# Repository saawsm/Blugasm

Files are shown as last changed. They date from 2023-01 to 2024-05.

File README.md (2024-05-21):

# Blugasm - A Bluetooth enabled Nogasm

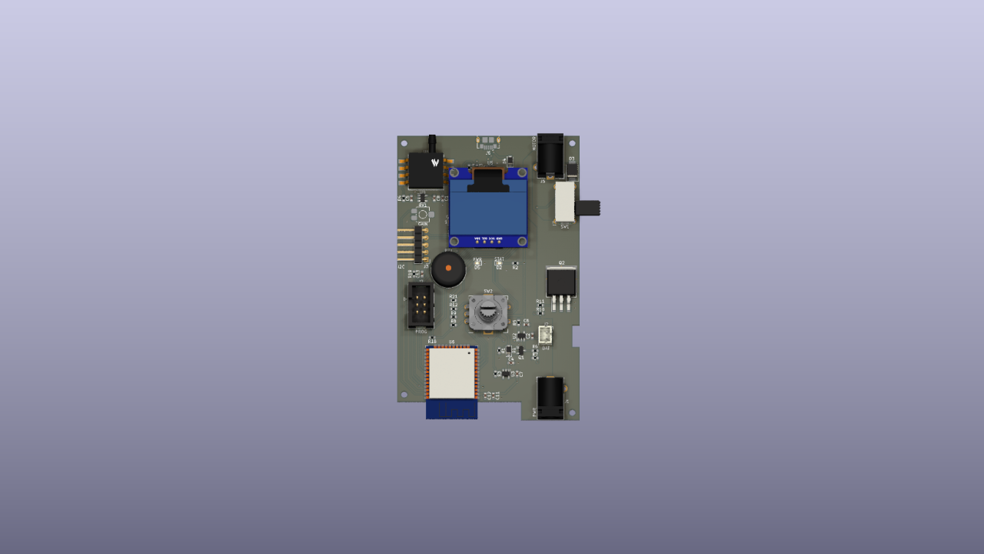
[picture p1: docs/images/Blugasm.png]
Blugasm


This project aims to predict and detect orgasms by using a pressure sensor (and optionally, additional I2C sensors such as SpO2 and/or GSR sensor) while controlling a vibrator.

The original design and concept comes from the [nogasm](https://github.com/nogasm/nogasm). It improves upon it by making it battery operated and Bluetooth enabled, thanks to the ESP-32 microcontroller.

## Acknowledgements
The design of this board was inspired/based off the [nogasm board](https://github.com/nogasm/nogasm).

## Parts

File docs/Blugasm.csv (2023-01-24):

Ref | Qty | Value | Description | MPN | MOUSER | LCSC
BZ1 | 1 | Buzzer | Buzzer, polarized | IE122303-1 | 497-IE122303-1
C1 | 1 | 10nF | Unpolarized capacitor, small symbol | CL10B103KB8NNNC | 187-CL10B103KB8NNNC | C1589
C2, C4, C6, C7 | 4 | 10uF | Unpolarized capacitor, small symbol | CL10A106MA8NRNC | 187-CL10A106MA8NRNC | C96446
C3 | 1 | 1uF | Unpolarized capacitor, small symbol | CL10B105KA8NFNC | 187-CL10B105KA8NFNC | C307479
C5 | 1 | 330nF | Unpolarized capacitor, small symbol | CL10B334KO8NNNC | 187-CL10B334KO8NNNC | C159798
C8, C9, C12, C13, C14, C15 | 6 | 100nF | Unpolarized capacitor, small symbol | CL10B104KB8NNWC | 187-CL10B104KB8NNNC | C1591
C10 | 1 | 4.7uF | Unpolarized capacitor, small symbol | CL10A475KQ8NNWC | 187-CL10A475KQ8NNWC | C3849923
C11 | 1 | 22uF | Unpolarized capacitor, small symbol | CL10A106MA8NRNC | 187-CL10A106MA8NRNC | C96446
D1, D4 | 2 | SS24FL | Schottky diode | SS24FL | 512-SS24FL | C894433
D2 | 1 | GREEN | Light emitting diode | 150060VS75000 | 710-150060VS75000
D3 | 1 | SSB44-E3 | Schottky diode, small symbol | SSB44-E3/52T | 625-SSB44-E3 | C466999
D5 | 1 | RED | Light emitting diode | 150060RS75000 | 710-150060RS75000
J1 | 1 | PWR | DC Barrel Jack with an internal switch | PJ-102AH | 490-PJ-102AH
J2 | 1 | BAT | Generic connector, single row, 01x02, script generated (kicad-library-utils/schlib/autogen/connector/)
J3 | 1 | I2C | Generic connector, single row, 01x05, script generated (kicad-library-utils/schlib/autogen/connector/)
J4 | 1 | OLED | 0.96" OLED Module I2C
J5 | 1 | MOTOR | DC Barrel Jack with an internal switch | PJ-102AH | 490-PJ-102AH
J6 | 1 | USB_B_Micro | USB Micro Type B connector | USB3076-30-A | 640-USB3076-30-A
J7 | 1 | PROG | Generic connector, double row, 02x03, odd/even pin numbering scheme (row 1 odd numbers, row 2 even numbers), script generated (kicad-library-utils/schlib/autogen/connector/)
Q1 | 1 | DMG3415U | P-MOSFET transistor, gate/source/drain | DMG3415UQ-7 | 621-DMG3415UQ-7 | C459537
Q2 | 1 | PHB32N06LT,118 | N-MOSFET transistor, gate/drain/source | PHB32N06LT,118 | 771-PHB32N06LT118 | C552626
Q3, Q4 | 2 | SS8050-G | NPN transistor, base/emitter/collector | SS8050-G | 750-SS8050-G | C164886
R1, R3, R6, R7 | 4 | 100k | Resistor | RC0603FR-07100KL | 603-RC0603FR-07100KL | C14675
R2, R5, R20, R22 | 4 | 4.7k | Resistor | RC0603FR-074K7L | 603-RC0603FR-074K7L | C99782
R4 | 1 | 750 | Resistor | RC0603FR-07750RL | 603-RC0603FR-07750RL | C114635
R10, R12, R15, R16, R18, R19 | 6 | 10k | Resistor | RC0603FR-0710KL | 603-RC0603FR-0710KL | C98220
R11, R23 | 2 | 100 | Resistor | RC0603FR-07100RL | 603-RC0603FR-07100RL | C105588
R13 | 1 | 22.1k | Resistor | RC0603FR-0722K1L | 603-RC0603FR-0722K1L | C137768
R14 | 1 | 47.5k | Resistor | RC0603FR-1047K5L | 603-RC0603FR-1047K5L | C4149630
R17, R21 | 2 | 1k | Resistor | RC0603FR-071KL | 603-RC0603FR-071KL | C22548
RV1 | 1 | GAIN | Trim-potentiometer | ST-4ETB103 | 229-ST-4ETB103 | C2922095
SW1 | 1 | PWR | Switch, dual pole double throw, separate symbols | EG2219 | 612-EG2219 | C3664594
SW2 | 1 | PEC11R-4220K-S0024 | Rotary encoder, dual channel, incremental quadrate outputs, with switch | PEC11R-4220K-S0024 | 652-PEC11R-4220K-S24
U1 | 1 | MP3V5050GP | 0 to 50 kPa Gauge Pressure Sensor | MP3V5050GP | 841-MP3V5050GP
U2 | 1 | MCP73831-2-OT | Single cell, Li-Ion/Li-Po charge management controller, 4.20V, Tri-State Status Output, in SOT23-5 package | MCP73831T-2ACI/OT | 579-MCP73831T-2ACIOT | C424093
U3 | 1 | AP2112K-3.3 | 600mA low dropout linear regulator, with enable pin, 3.8V-6V input voltage range, 3.3V fixed positive output, SOT-23-5 | AP2112K-3.3TRG1 | 621-AP2112K-3.3TRG1 | C51118
U4 | 1 | MCP6001-OT | 1MHz, Low-Power Op Amp, SOT-23-5 | MCP6001RT-I/OT | 579-MCP6001RT-I/OT | C154973
U5 | 1 | CP2102N-A02-GQFN24 | USB to UART master bridge, QFN-24 | CP2102N-A02-GQFN24R | 634-CP2102NA02QFN24R | C969151
U6 | 1 | ESP32-WROOM-32E | RF Module, ESP32-D0WD SoC, Wi-Fi 802.11b/g/n, Bluetooth, BLE, 32-bit, 2.7-3.6V, onboard antenna, SMD | ESP32-WROOM-32E-N16 | 356-ESP32WRM32E128PH | C701343

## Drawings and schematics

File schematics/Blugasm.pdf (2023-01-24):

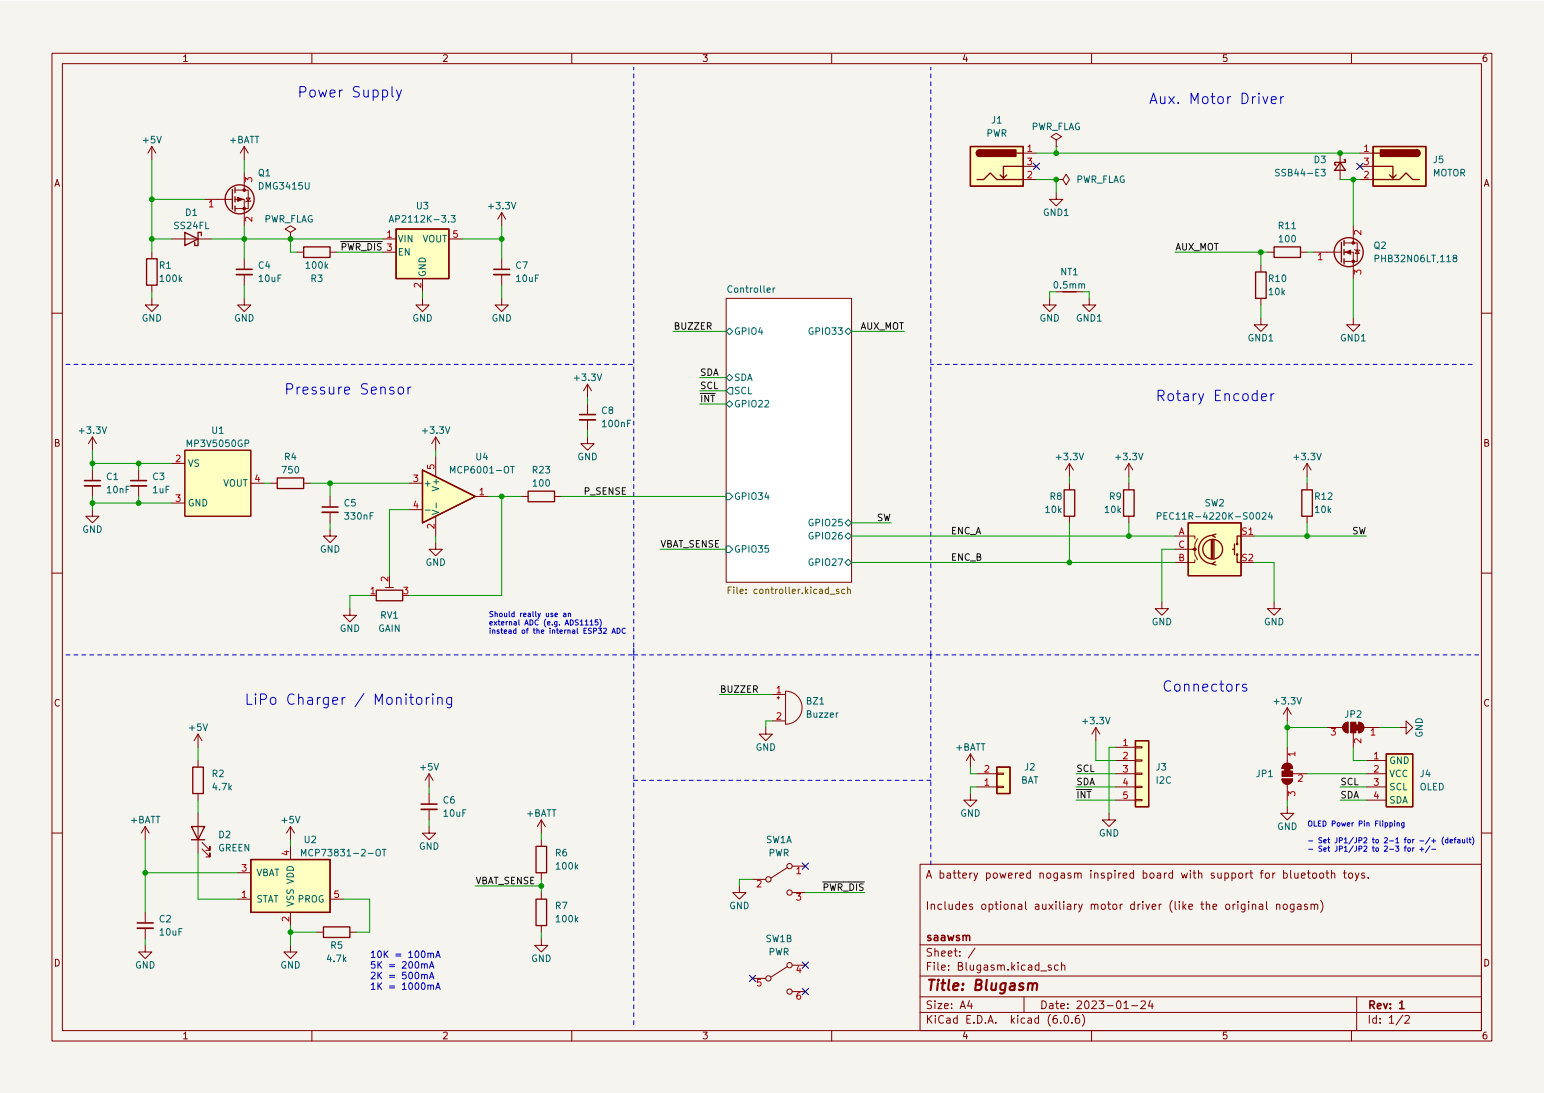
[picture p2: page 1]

instead of the internal ESP32 ADC Pressure Sensor

Should really use an
external ADC (e.g. ADS1115)

- Set JP1/JP2 to 2-1 for -/+ (default)
- Set JP1/JP2 to 2-3 for +/-

A battery powered nogasm inspired board with support for bluetooth toys.

Includes optional auxiliary motor driver (like the original nogasm)

File: Blugasm.kicad_sch Sheet: / saawsm

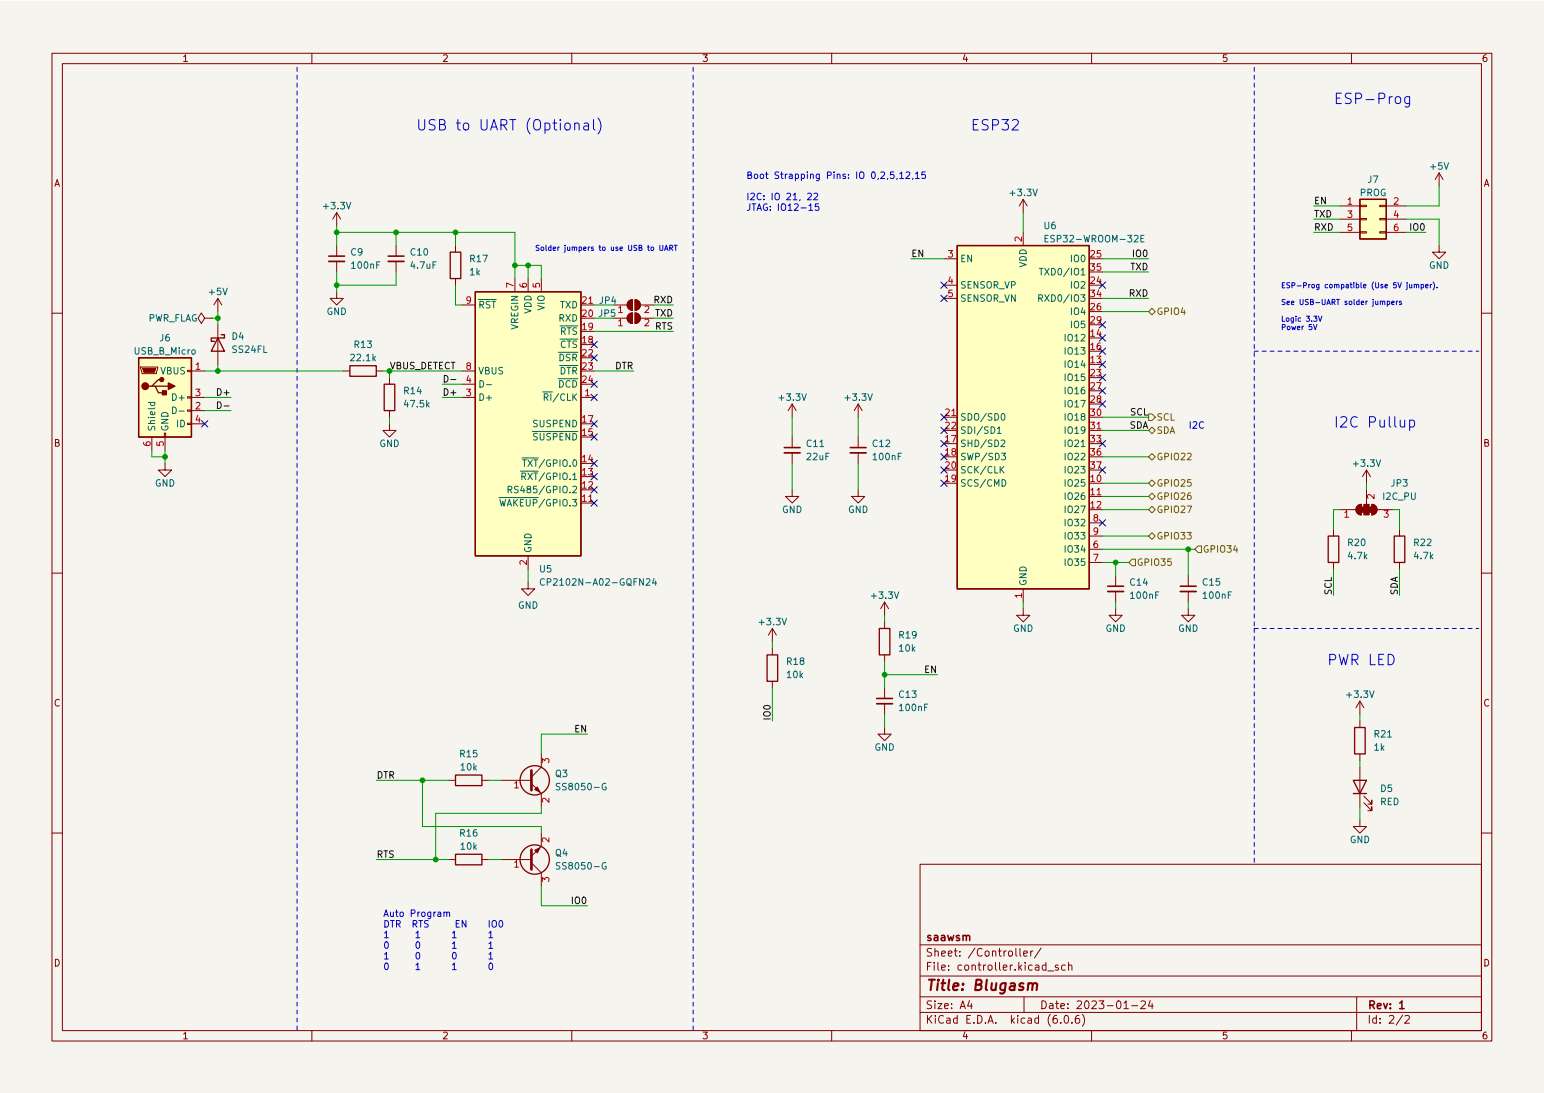
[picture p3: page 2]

Solder jumpers to use USB to UART USB to UART (Optional)

Power 5V Boot Strapping Pins: IO 0,2,5,12,15

2 SCK/CLK 20 SDO/SD0 21 SDI/SD1 22

ESP-Prog compatible (Use 5V jumper). See USB-UART solder jumpers Logic 3.3V

2 RXD 20 TXD 21 ~{DSR}22 ~{DTR}23 ~{DCD}24 D+ 3 D- 4 VIO

File: controller.kicad_sch Sheet: /Controller/ saawsm

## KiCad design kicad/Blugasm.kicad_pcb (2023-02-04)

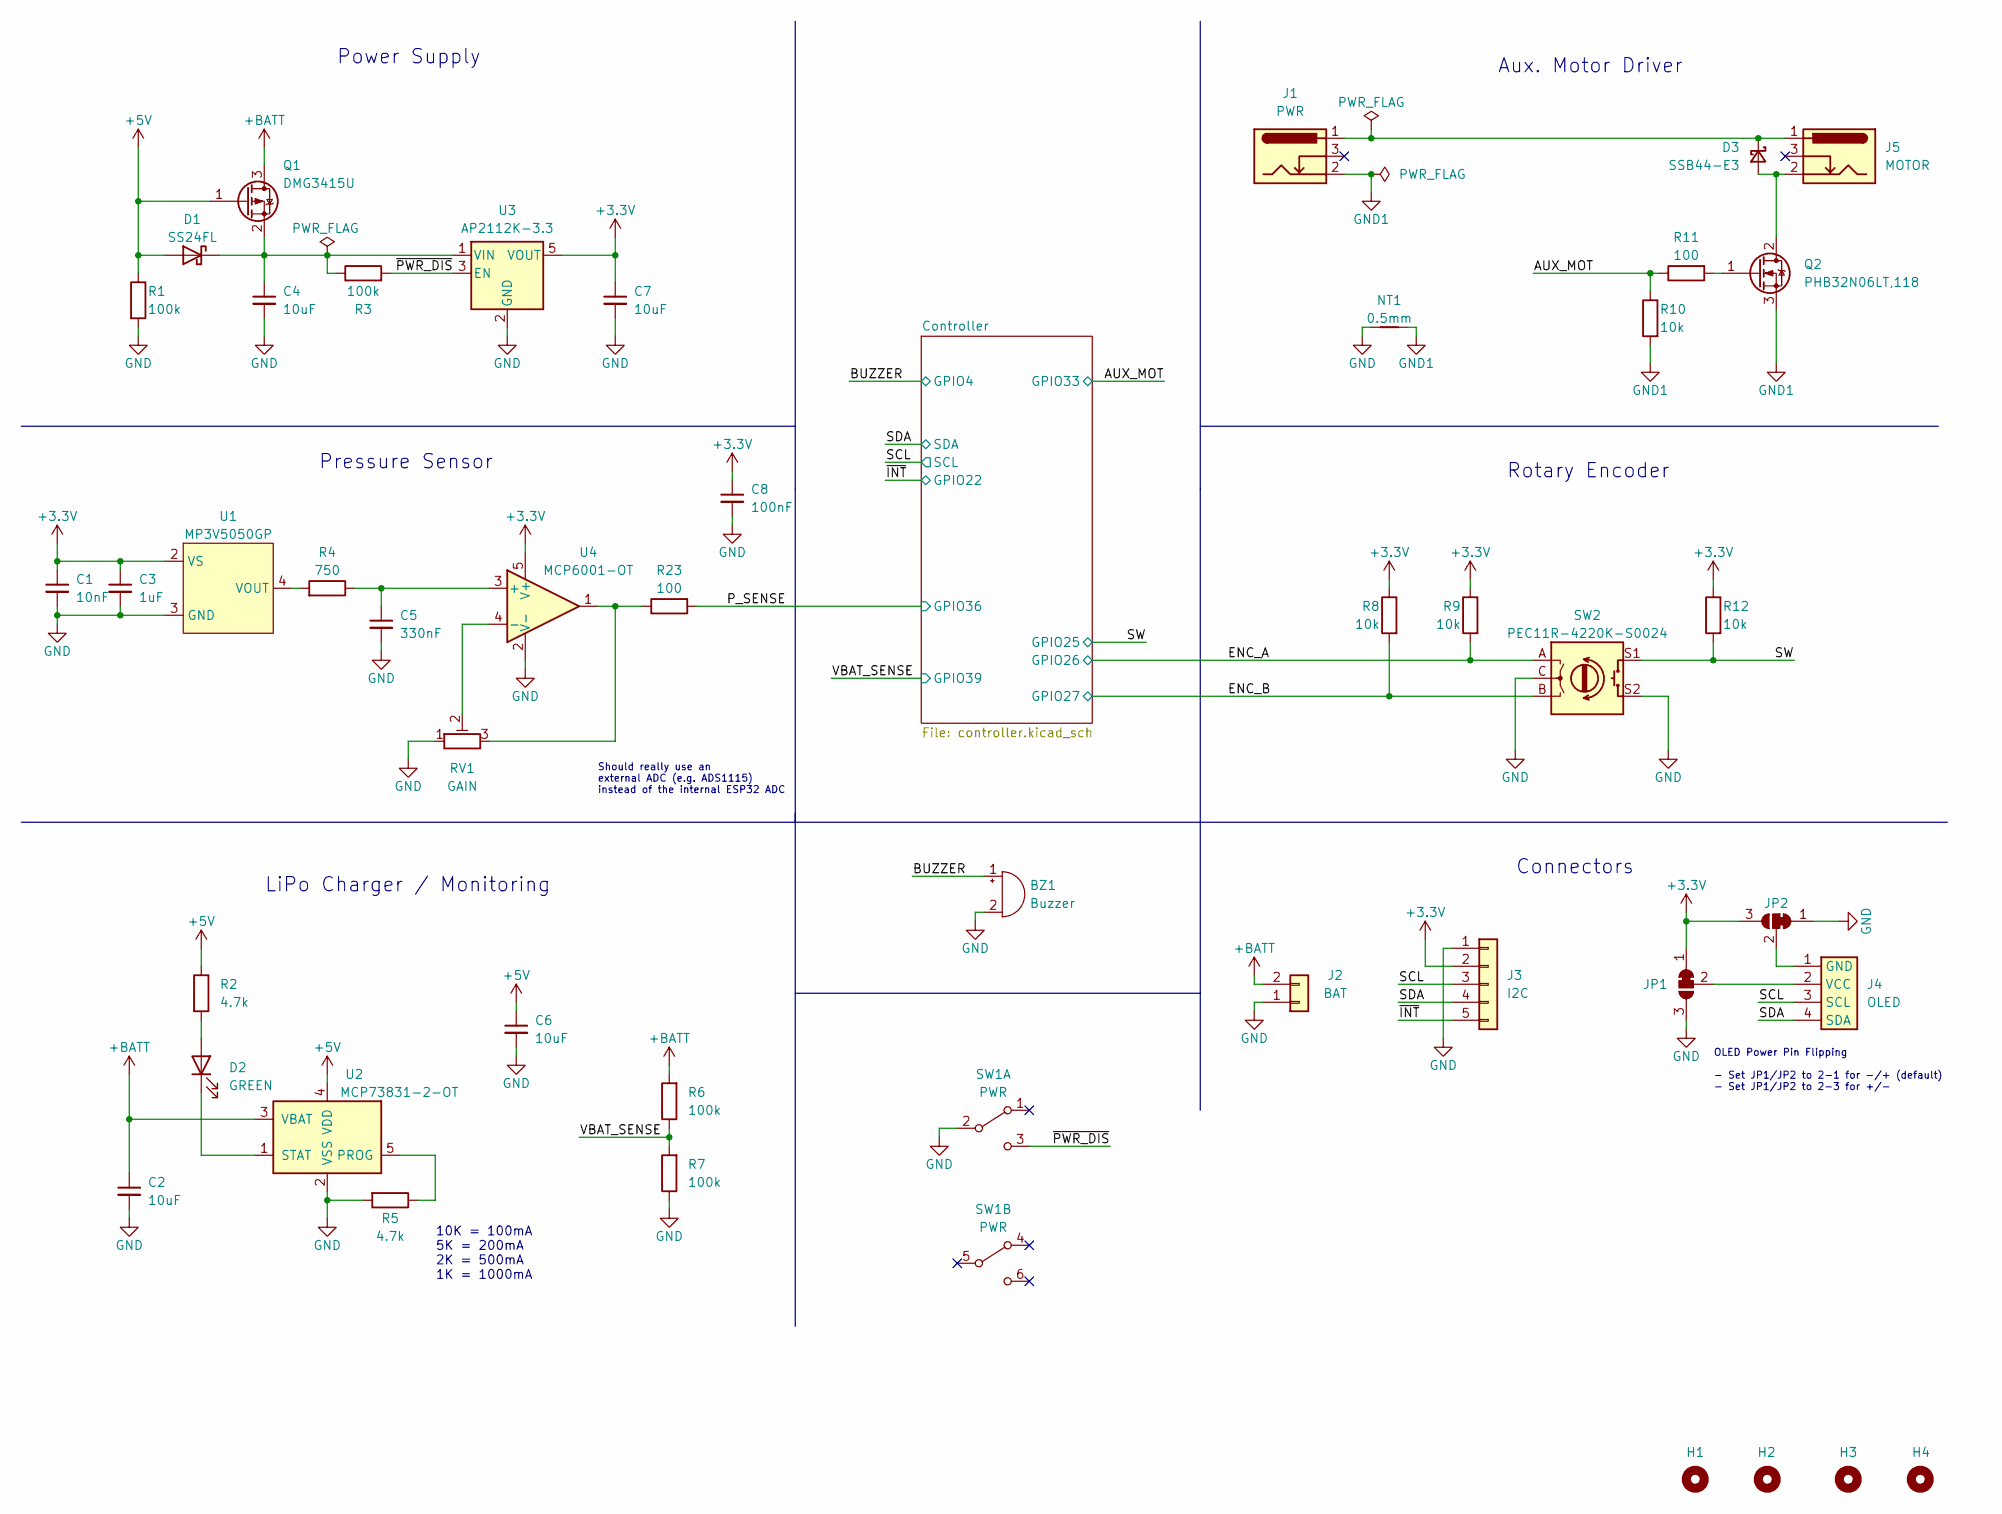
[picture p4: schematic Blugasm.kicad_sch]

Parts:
BZ1: Buzzer; Buzzer_12x9.5RM7.6; MPN IE122303-1; MOUSER 497-IE122303-1
C1: 10nF; C_0603_1608Metric; MPN CL10B103KB8NNNC; LCSC C1589
C2, C4, C6, C7: 10uF; C_0603_1608Metric; MPN CL10A106MA8NRNC; LCSC C96446
C3: 1uF; C_0603_1608Metric; MPN CL10B105KA8NFNC; LCSC C307479
C5: 330nF; C_0603_1608Metric; MPN CL10B334KO8NNNC; LCSC C159798
C8: 100nF; C_0603_1608Metric; MPN CL10B104KB8NNWC; LCSC C1591
D1: SS24FL; D_SOD-123F; MPN SS24FL; LCSC C894433
D2: GREEN; LED_0603_1608Metric; MPN 150060VS75000; MOUSER 710-150060VS75000
D3: SSB44-E3; D_SMB; MPN SSB44-E3/52T; LCSC C466999
H1, H2, H3, H4: MountingHole; MountingHole_2.2mm_M2
J1: PWR; BarrelJack_CUI_PJ-102AH_Horizontal; MPN PJ-102AH; MOUSER 490-PJ-102AH
J2: BAT; JST_PH_B2B-PH-K_1x02_P2.00mm_Vertical
J3: I2C; PinHeader_1x05_P2.54mm_Horizontal
J4: OLED; OLED_I2C
J5: MOTOR; BarrelJack_CUI_PJ-102AH_Horizontal; MPN PJ-102AH; MOUSER 490-PJ-102AH
JP1, JP2: SolderJumper_3_Bridged12; SolderJumper-3_P1.3mm_Bridged12_Pad1.0x1.5mm_NumberLabels
NT1: 0.5mm; NetTie-2_SMD_Pad0.5mm
Q1: DMG3415U; SOT-23; MPN DMG3415UQ-7; LCSC C459537
Q2: PHB32N06LT,118; TO-263-3_TabPin2; MPN PHB32N06LT,118; LCSC C552626
R1, R3, R6, R7: 100k; R_0603_1608Metric; MPN RC0603FR-07100KL; LCSC C14675
R2, R5: 4.7k; R_0603_1608Metric; MPN RC0603FR-074K7L; LCSC C99782
R4: 750; R_0603_1608Metric; MPN RC0603FR-07750RL; LCSC C114635
R8, R9, R10, R12: 10k; R_0603_1608Metric; MPN RC0603FR-0710KL; LCSC C98220
R11, R23: 100; R_0603_1608Metric; MPN RC0603FR-07100RL; LCSC C105588
RV1: GAIN; ST-4EB; MPN ST-4ETB103; LCSC C2922095
SW1: PWR; SW_E-Switch_EG2219_DPDT_Angled; MPN EG2219; MOUSER 612-EG2219
SW2: PEC11R-4220K-S0024; Rotary_Encoder_Switched_PEC11R; MPN PEC11R-4220K-S0024; MOUSER 652-PEC11R-4220K-S24
U1: MP3V5050GP; MP3V5050; MPN MP3V5050GP; MOUSER 841-MP3V5050GP
U2: MCP73831-2-OT; SOT-23-5; MPN MCP73831T-2ACI/OT; LCSC C424093
U3: AP2112K-3.3; SOT-23-5; MPN AP2112K-3.3TRG1; LCSC C51118
U4: MCP6001-OT; SOT-23-5; MPN MCP6001RT-I/OT; MOUSER 579-MCP6001RT-I/OT

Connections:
+3.3V: C1.1, C3.1, C7.1, C8.1, J3.2, JP1.1 (A), JP2.3 (B), R8.1, R9.1, R12.1, U1.2 (VS), U3.5 (VOUT), U4.5 (V+); also elsewhere on the board
+5V: C6.1, D1.2 (A), Q1.1 (G), R1.1, R2.1, U2.4 (VDD); also elsewhere on the board
+BATT: C2.1, J2.2, Q1.3 (D), R6.2, U2.3 (VBAT)
/AUX_MOT: R10.1, R11.1; also elsewhere on the board
/BUZZER: BZ1.1 (-); also elsewhere on the board
/ENC_A: R9.2, SW2.A; also elsewhere on the board
/ENC_B: R8.2, SW2.B; also elsewhere on the board
/P_SENSE: R23.2; also elsewhere on the board
/SCL: J3.3, J4.3 (SCL); also elsewhere on the board
/SDA: J3.4, J4.4 (SDA); also elsewhere on the board
/SW: R12.2, SW2.S1; also elsewhere on the board
/VBAT_SENSE: R6.1, R7.2; also elsewhere on the board
/~INT: J3.5; also elsewhere on the board
/~PWR_DIS: R3.2, SW1.3 (C), U3.3 (EN)
GND: BZ1.2 (+), C1.2, C2.2, C3.2, C4.2, C5.2, C6.2, C7.2, C8.2, J2.1, J3.1, JP1.3 (B), JP2.1 (A), NT1.1, R1.2, R5.2, R7.1, RV1.1, SW1.2 (B), SW2.C, SW2.S2, U1.3 (GND), U2.2 (VSS), U3.2 (GND), U4.2 (V-); also elsewhere on the board
GND1: J1.2, NT1.2, Q2.3 (S), R10.2
unnamed: C4.1, D1.1 (K), Q1.2 (S), R3.1, U3.1 (VIN)
unnamed: C5.1, R4.1, U4.3 (+)
unnamed: D2.1 (K), U2.1 (STAT)
unnamed: D2.2 (A), R2.2
unnamed: D3.1 (K), J1.1, J5.1
unnamed: D3.2 (A), J5.2, Q2.2 (D)
unnamed: J4.1 (GND), JP2.2 (C)
unnamed: J4.2 (VCC), JP1.2 (C)
unnamed: Q2.1 (G), R11.2
unnamed: R4.2, U1.4 (VOUT)
unnamed: R5.1, U2.5 (PROG)
unnamed: R23.1, RV1.3, U4.1
unnamed: RV1.2, U4.4 (-)

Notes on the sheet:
Should really use an external ADC (e.g. ADS1115) instead of the internal ESP32 ADC
Aux. Motor Driver
Connectors
OLED Power Pin Flipping - Set JP1/JP2 to 2-1 for -/+ (default) - Set JP1/JP2 to 2-3 for +/-
10K = 100mA 5K = 200mA 2K = 500mA 1K = 1000mA
Rotary Encoder
Pressure Sensor
Power Supply
LiPo Charger / Monitoring

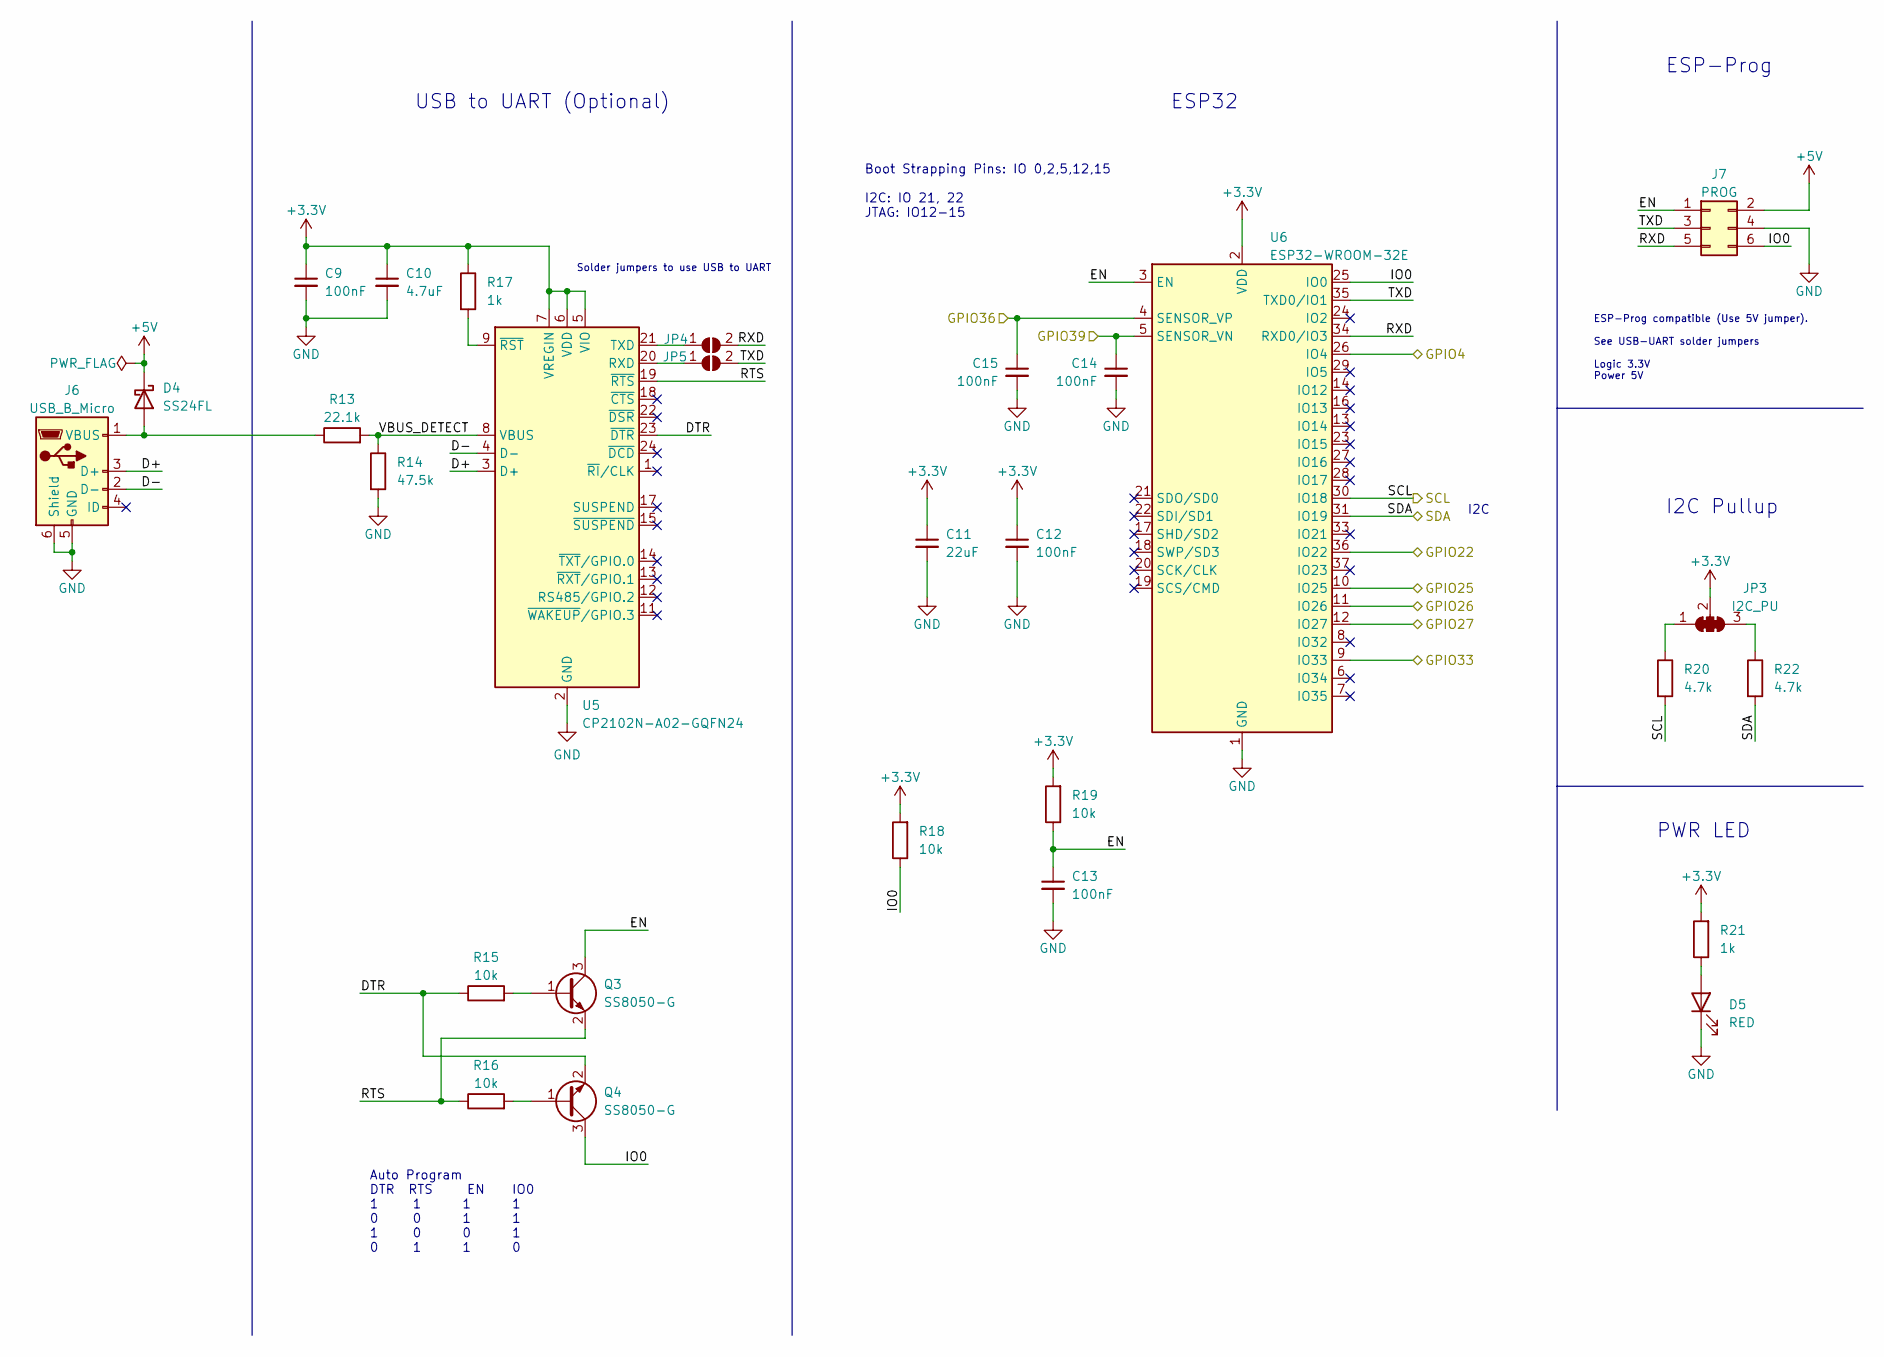
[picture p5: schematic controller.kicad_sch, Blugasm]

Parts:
C9, C12, C13, C14, C15: 100nF; C_0603_1608Metric; MPN CL10B104KB8NNWC; LCSC C1591
C10: 4.7uF; C_0603_1608Metric; MPN CL10A475KQ8NNWC; LCSC C3849923
C11: 22uF; C_0603_1608Metric; MPN CL10A106MA8NRNC; LCSC C96446
D4: SS24FL; D_SOD-123F; MPN SS24FL; LCSC C894433
D5: RED; LED_0603_1608Metric; MPN 150060RS75000; MOUSER 710-150060RS75000
J6: USB_B_Micro; USB_Micro-B_GCT_USB3076-30-A; MPN USB3076-30-A; MOUSER 640-USB3076-30-A
J7: PROG; IDC-Header_2x03_P2.54mm_Vertical
JP3: I2C_PU; SolderJumper-3_P1.3mm_Bridged123_Pad1.0x1.5mm_NumberLabels
JP4: UART_TXD; SolderJumper-2_P1.3mm_Open_RoundedPad1.0x1.5mm
JP5: UART_RXD; SolderJumper-2_P1.3mm_Open_RoundedPad1.0x1.5mm
Q3, Q4: SS8050-G; SOT-23; MPN SS8050-G; LCSC C164886
R13: 22.1k; R_0603_1608Metric; MPN RC0603FR-0722K1L; LCSC C137768
R14: 47.5k; R_0603_1608Metric; MPN RC0603FR-1047K5L; LCSC C4149630
R15, R16, R18, R19: 10k; R_0603_1608Metric; MPN RC0603FR-0710KL; LCSC C98220
R17, R21: 1k; R_0603_1608Metric; MPN RC0603FR-071KL; LCSC C22548
R20, R22: 4.7k; R_0603_1608Metric; MPN RC0603FR-074K7L; LCSC C99782
U5: CP2102N-A02-GQFN24; QFN-24-1EP_4x4mm_P0.5mm_EP2.6x2.6mm; MPN CP2102N-A02-GQFN24R; LCSC C969151
U6: ESP32-WROOM-32E; ESP32-WROOM-32; MPN ESP32-WROOM-32E-N16; LCSC C701343

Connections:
+3.3V: C9.1, C10.1, C11.1, C12.1, JP3.2 (C), R17.1, R18.2, R19.2, R21.2, U5.5 (VIO), U5.6 (VDD), U5.7 (VREGIN), U6.2 (VDD); also elsewhere on the board
+5V: D4.1 (K), J7.2; also elsewhere on the board
/AUX_MOT: U6.9 (IO33); also elsewhere on the board
/BUZZER: U6.26 (IO4); also elsewhere on the board
/Controller/D+: J6.3 (D+), U5.3 (D+)
/Controller/D-: J6.2 (D-), U5.4 (D-)
/Controller/DTR: Q4.2 (E), R15.1, U5.23 (~DTR)
/Controller/EN: C13.1, J7.1, Q3.3 (C), R19.1, U6.3 (EN)
/Controller/IO0: J7.6, Q4.3 (C), R18.1, U6.25 (IO0)
/Controller/RTS: Q3.2 (E), R16.1, U5.19 (~RTS)
/Controller/RXD: J7.5, JP4.2 (B), U6.34 (RXD0/IO3)
/Controller/TXD: J7.3, JP5.2 (B), U6.35 (TXD0/IO1)
/Controller/VBUS_DETECT: R13.2, R14.1, U5.8 (VBUS)
/ENC_A: U6.11 (IO26); also elsewhere on the board
/ENC_B: U6.12 (IO27); also elsewhere on the board
/P_SENSE: C15.1, U6.4 (SENSOR_VP); also elsewhere on the board
/SCL: R20.2, U6.30 (IO18); also elsewhere on the board
/SDA: R22.2, U6.31 (IO19); also elsewhere on the board
/SW: U6.10 (IO25); also elsewhere on the board
/VBAT_SENSE: C14.1, U6.5 (SENSOR_VN); also elsewhere on the board
/~INT: U6.36 (IO22); also elsewhere on the board
GND: C9.2, C10.2, C11.2, C12.2, C13.2, C14.2, C15.2, D5.1 (K), J6.5 (GND), J6.6 (Shield), J7.4, R14.2, U5.2 (GND), U5.25 (GND), U6.1 (GND), U6.15 (GND), U6.38 (GND), U6.39 (GND); also elsewhere on the board
unnamed: D4.2 (A), J6.1 (VBUS), R13.1
unnamed: D5.2 (A), R21.1
unnamed: JP3.1 (A), R20.1
unnamed: JP3.3 (B), R22.1
unnamed: JP4.1 (A), U5.21 (TXD)
unnamed: JP5.1 (A), U5.20 (RXD)
unnamed: Q3.1 (B), R15.2
unnamed: Q4.1 (B), R16.2
unnamed: R17.2, U5.9 (~RST)

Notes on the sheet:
ESP32
PWR LED
ESP-Prog
I2C Pullup
Solder jumpers to use USB to UART
I2C
USB to UART (Optional)
Boot Strapping Pins: IO 0,2,5,12,15 I2C: IO 21, 22 JTAG: IO12-15
Auto Program DTR RTS EN IO0 1 1 1 1 0 0 1 1 1 0 0 1 0 1 1 0
ESP-Prog compatible (Use 5V jumper). See USB-UART solder jumpers Logic 3.3V Power 5V

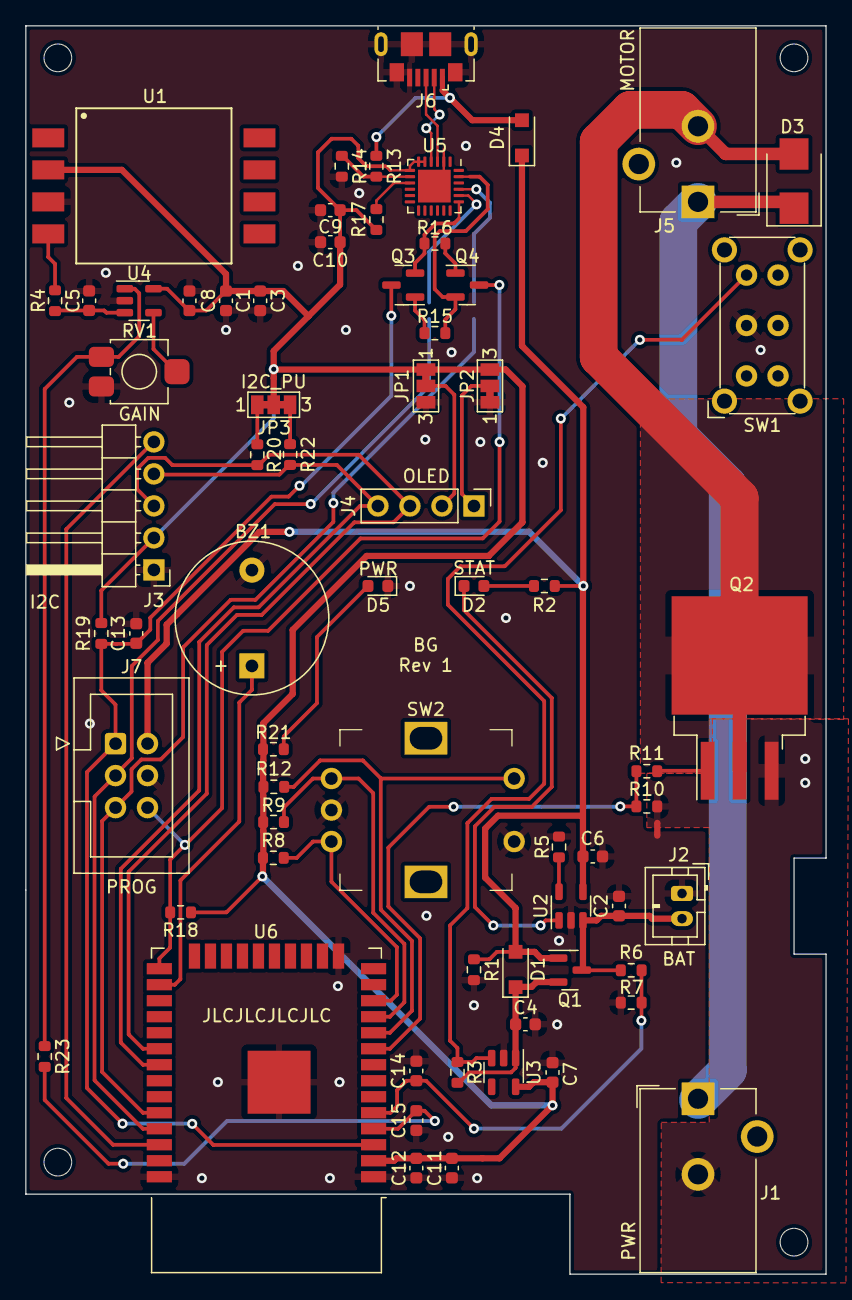
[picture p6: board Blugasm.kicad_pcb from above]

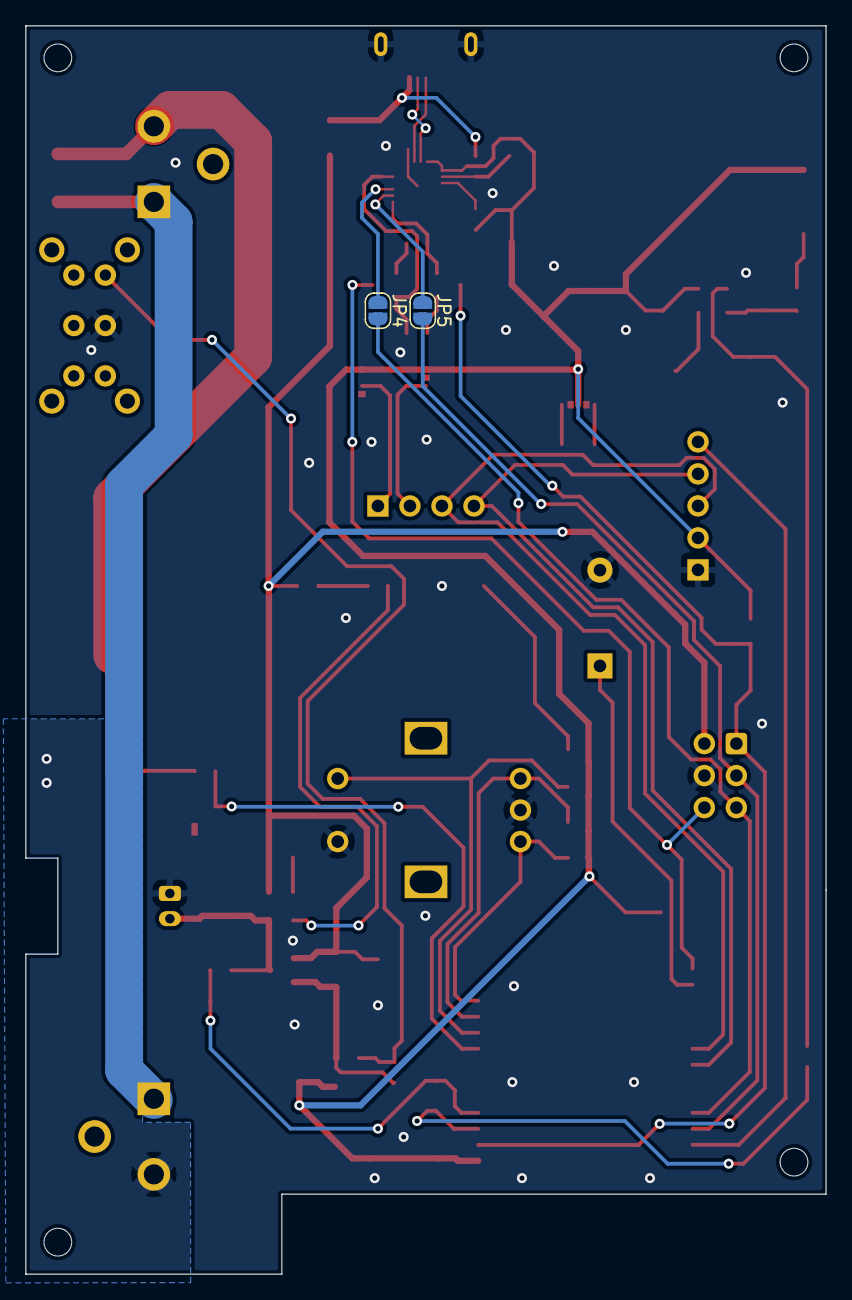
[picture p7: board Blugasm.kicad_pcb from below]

Board: 2 copper layers, 63.5 x 99.1 mm, 74 parts (2 on the bottom side), 47 nets.

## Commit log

2022-01-31 move to pcb folder
    [Blugasm.kicad_pcb, Blugasm.kicad_sch, controller.kicad_sch]
2022-01-31 add schematic pdf
    [Blugasm.kicad_sch]
2022-02-02 assign footprints
    [Blugasm.kicad_sch, controller.kicad_sch]
2022-02-02 update dru
    [Blugasm.kicad_pcb]
2023-01-17 add pcb
    [Blugasm.csv, Blugasm.kicad_pcb, Blugasm.kicad_sch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]
2023-01-24 fix incorrect footprint
    [Blugasm.csv, Blugasm.kicad_pcb, Blugasm.kicad_sch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]
2023-02-04 use sensor_vp/vn for ADC
    [Blugasm.kicad_pcb, Blugasm.kicad_sch, controller.kicad_sch]
